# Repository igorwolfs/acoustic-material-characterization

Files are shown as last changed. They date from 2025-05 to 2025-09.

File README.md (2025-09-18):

# acoustic-emissions-hw
Repository for my non-destructive mechanical measurement device.

## Project Goal
Being able to measure cracks and holes in welds and solid materials by measuring mechanical wave behavior in the material.

## Description
The project will consist of 3 boards
- acoustic-processing-hw (The compute-module)
- acoustic-preamp-hw (The preamp-module)
- acoustic-piezodriver-hw (The driver-module)

## The electronics demistified

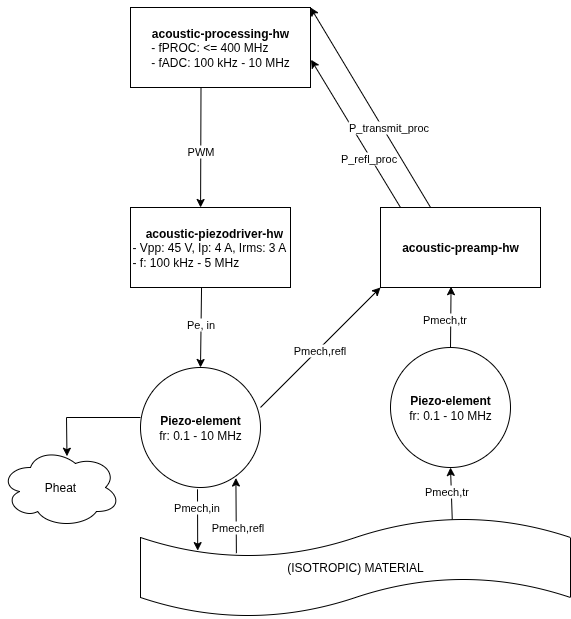
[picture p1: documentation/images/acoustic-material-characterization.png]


The **compute**-module will drive a PWM signal to the **driver**-module. The **driver** contains various DC-DC converters, along with a single-phase inverter. 

The inverter-output is connected to a piezo-element, driving the piezo-element with a 0.1 MHz - 10 MHz block-wave at an amplitude of 40 V, and currents up to 3 A RMS. Optional piezo-specific band-pass filters might be integrated.

The "transmitting" piezo-element and "receiving" piezo-element are connected to the **preamp** board, capable of
- Measuring transmitted power through the sending piezo.
- Measuring reflections back into the sending piezo (due to e.g.: mechanical impedance discontinuities between sending and receiving piezo).
- Measuring received power at the receiving piezo.

The **preamp** board will likely be covering only part of the 0.1-10 MHz frequency band. After some active filtering on the **preamp**-board, the signal is passed onto the front-end present on the **processing**-board. The **processing** board buffers the signal coming from the **preamp** and samples it with 10-bit accuracy at maximum 35 MHz.

## The mechanics demistified
#### Initial piezo-choice
The initial test-piezo used is the [UB161M7](https://www.mouser.de/datasheet/2/334/UB161M7-953231.pdf), which has a resonance frequency of 1.70 MHz.

#### Isotropic behavior
In order to get the best possible results, in terms of wave propagation insights and material properties. Ideally isotropic materials are used. Anisotropic materials will likely require lots of calibration and specific digital processing.

#### Piezo resonance frequency
In order to pass on vibration from the piezo onto the material, it's imperative to match their acoustic impedances. This will likely dampen the resonance curve, and shift the resonance frequency of the piezo.

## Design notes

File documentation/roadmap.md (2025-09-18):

# 1. Research
## Physics
### Wave mechanics
&#9745; Make sure you understand the terms in the wave equation
- &#9745;  The different types of waves (longitudinal vs transverse)
- &#9745;  Difference between elastic vs acoustic
	- Homogenous vs heterogenous materials

### Piezo-electrics
- Make sure you understand how the piezo-electric effect works
- how the piezo-electric material turns the mechanical energy into electrical energy on a molecular / atomic level.

## Piezo-electronics
- Choose the correct resonance frequency depending on the materials

# 2. Design
## Piezo
### Electrical simulation
- &#9745;  Create an equivalent resonant circuit for the piezo-element to use in LTSpice-simulations

### Mechanical simulation
- Think about mechanical adaptations for waterproofing / impedance matching / inital testing

## Driving electronics
### Driving inverter
- &#9745; Design / dimension the driving inverter and simulate in ltspice together with the piezo-electric
- Create in KiCad
	- Make sure to generate 12 volts from a buck converter
	- Add a possibility to simply supply the FET driver with volts in order to test shoot-through currents and things like that
		- This way you won't need to deal with those at 20 volts
- Add enough capacitance to supply the 10 amp current peaks to the piezo.

### Connector
- Choose an appropriate connector type for the driving part
	- Simply put 2 very big pads, one for each inverter side.
		- If needed solder some high-power connectors onto them / Make sure to have some holes ready.
	- Use a high-power twisted wire to connect them both.

## Analog front-end
### ADC selection
- Choose an ADC which can sample up to 10 MHz (so we can drive Piezo's up to 5 MHz)
	- Design circuitry around it, make sure it is isolated from the inverter

- Check design circuit for existing examples
	- Choose differential mode inputs
	- Choose Vref 2 Volt initially, make sure it's modifiable later-on to 1 V

### Pre-amplifier
- Design a preamp with a low source impedance to push the piezo through the cable
- Make sure you can integrate the preamp with the sensor
- Think about waiting with the preamp, and doing initial receiver measurements with an oscilloscope first.
	- Depending on whether you can fit everything on one board or not.

### Connector
- Choose an appropriate connector for transmitting the amplified signal.
	- See if you can use the same one for the driving part as you can for the sensing part (not necessarily)

## Digital electronics

### PWM generation
- Use an FPGA
	- Make sure to add dead time to the inverter

### FPGA Selection
- Check existing ultrasound projects using FPGA's, to see how the pipeline typically looks (e.g.: lit3rick, un0rick) -> done

#### Booting the FPGA
- Decide on how to boot the FPGA
	- Preview a JTAG connection
	- preview a QSPI memory interface
		- Quad-SPI, check the required configuration for the EC5
		- Check if there are any cores for the QSPI

# 3. Setup

## Piezo-electric transducer availability
- Buy the piezo-electric (UB161M7)
	- Buy at DigiKey: https://www.digikey.de/en/products/detail/pui-audio-inc/UB161M7/6071956
	- Circular shape, positive internal ring, negative external ring (good for shear waves)
	- resonance frequency: 1.7 MHz
- Characterize the piezo-element with a VNA
	- Check the source impedance, The resonance frequency, The resonance impedance
	- Make / Buy an SMA to 2-terminal adapter so you can simply connect your piezo-electric element.
	- Make sure to calibrate the end of the SMA using a 50 ohm resistance with MINIMAL PARASITICS
	- Encapsulate 2 of them in a transparent, electrically insulating layer (epoxy, RTV silicone, Parylene)
		- Make sure the impedance is appropriate for transferring vibrations to other materials.

## Driving the piezo
### Waveform
- Check if a bandpass filter is needed to filter out the high / low frequency components
	- We're getting pretty close to the limits of what the FET driver + FET can do at 4-5 MHz.

## Analog front-end adaptations

### ADC adaptations
- Depending on the Vpp coing out of your ADC
	- Adapt your Vref to 1 V instead of 2 V

### LNA design
- Perform this design after having the piezo-element receiver and measuring Vpp with an oscilloscope
	- If this Vpp is high enough

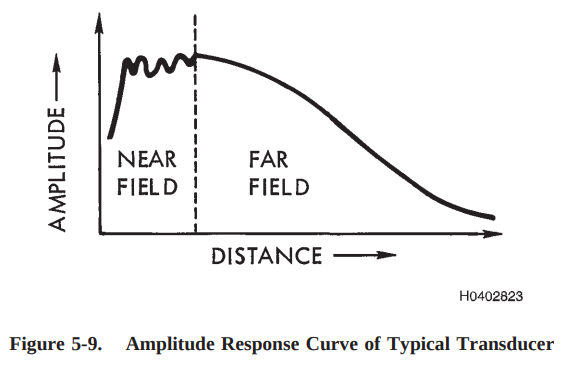
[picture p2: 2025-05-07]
piezo-research/theory/images/beam_spread.png

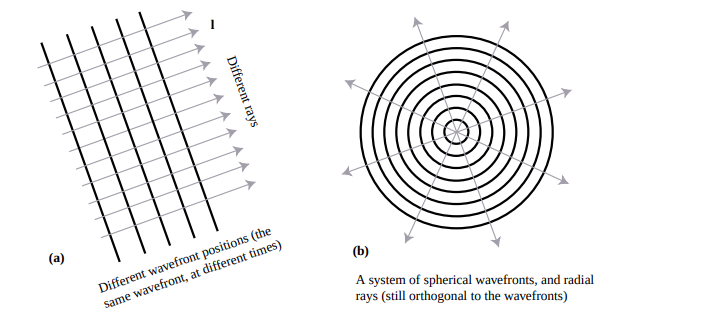
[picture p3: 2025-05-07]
piezo-research/theory/images/wavefronts.png

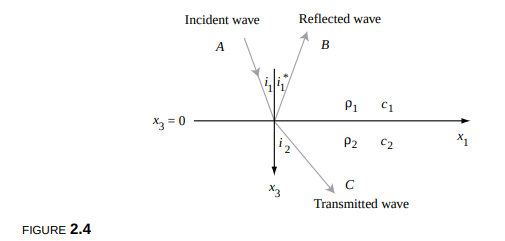
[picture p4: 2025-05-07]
piezo-research/theory/images/planar_interface.png

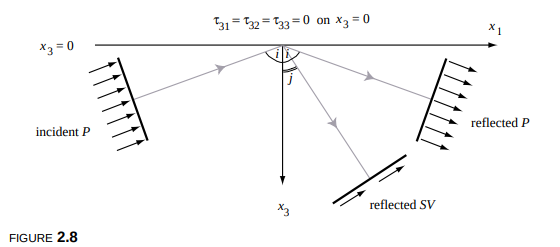
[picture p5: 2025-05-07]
piezo-research/theory/images/elastic_interface.png

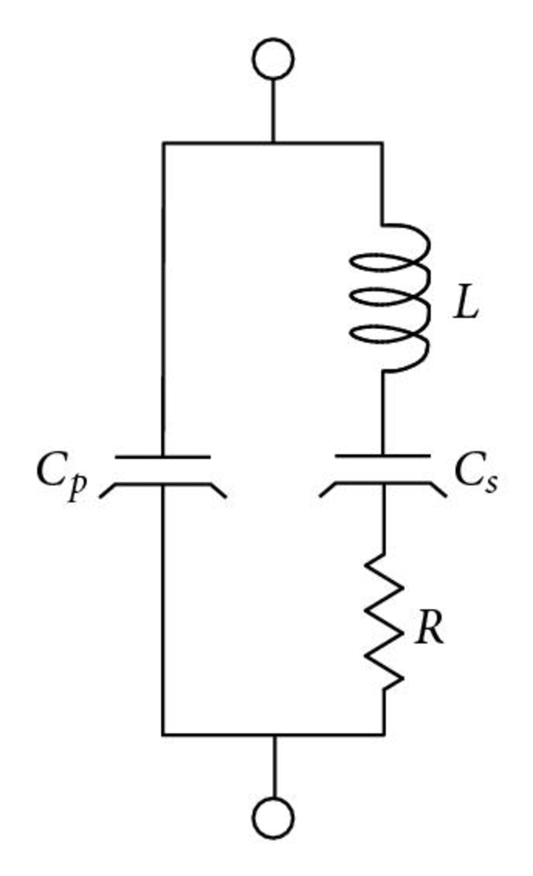
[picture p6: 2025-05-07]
piezo-research/theory/images/BVD.png

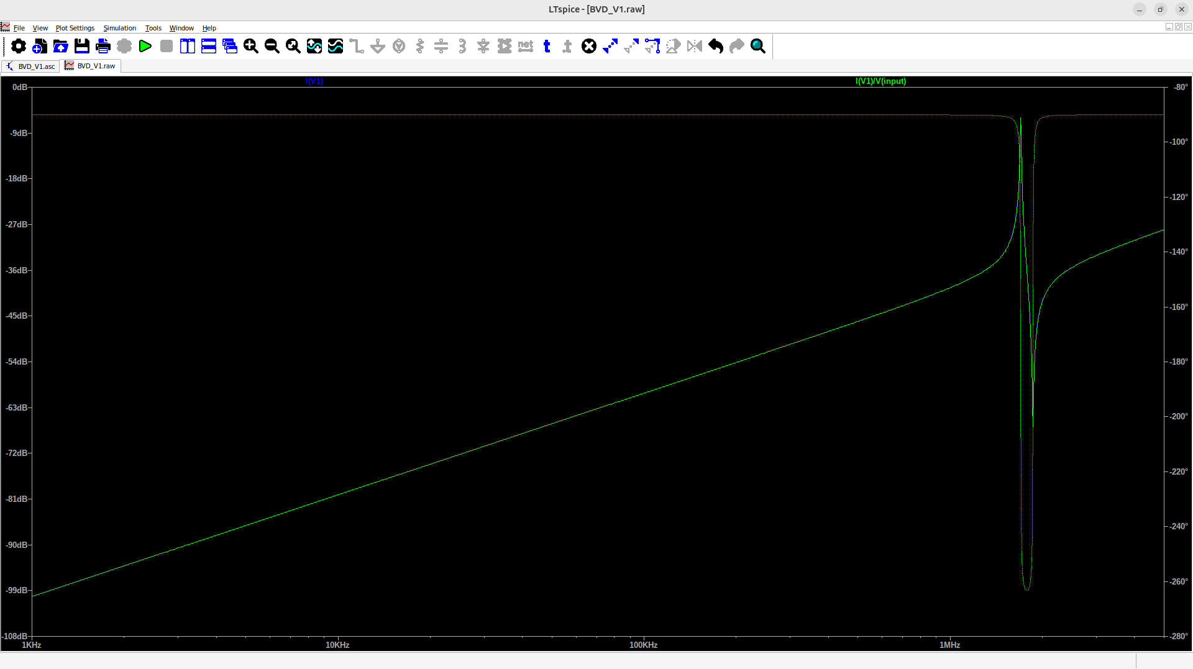
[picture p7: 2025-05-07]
piezo-research/write-ups/images/BVD_v1.png

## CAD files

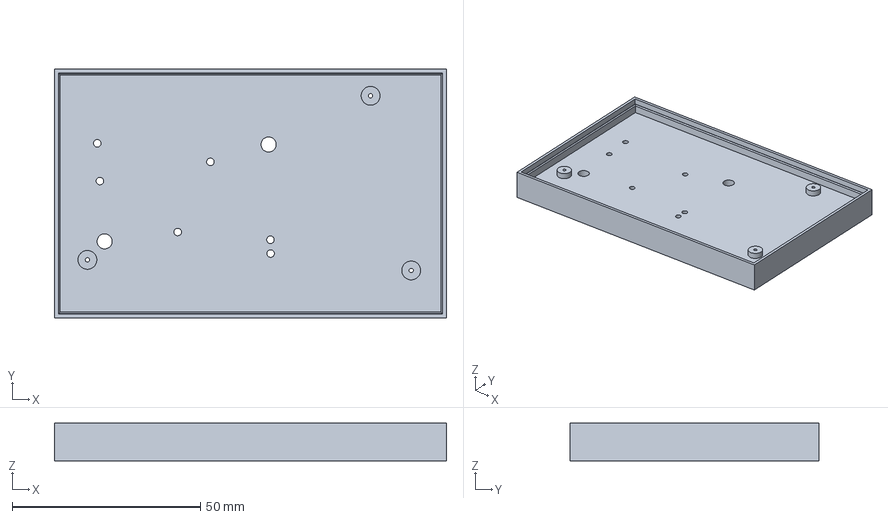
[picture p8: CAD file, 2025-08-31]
setup/cases/case_1/piezodriver_case.FCStd
104.0 x 66.0 x 10.0 mm

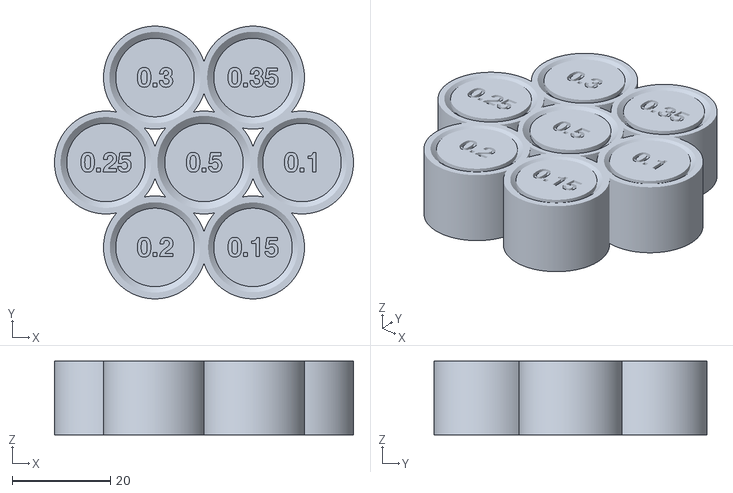
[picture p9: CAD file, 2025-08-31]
setup/cases/tolerance_tests/v2/tolerance_test.stl
61.0 x 55.6 x 15.0

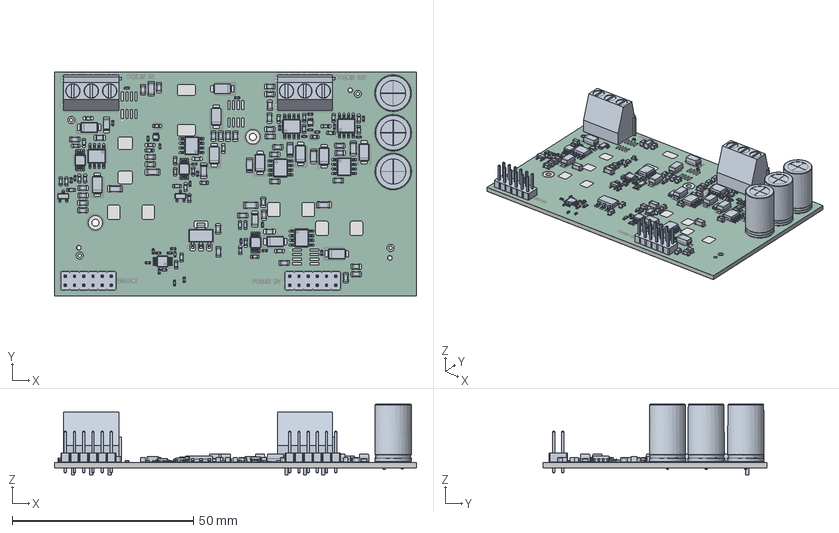
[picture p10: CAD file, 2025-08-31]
setup/cases/case_1/acoustic-piezodriver-board.step
100.0 x 62.0 x 19.5 mm
R_0603_1608Metric x 32
PinHeader_2x06_P2.54mm_Vertical x 2
C_0805_2012Metric x 34
C_0603_1608Metric x 3
C_0402_1005Metric x 24
R_0402_1005Metric x 8
VSSOP-8_3x3mm_P0.65mm x 3
D_SMA x 11
TerminalBlock_Phoenix_MKDS-1,5-3-5.08_1x03_P5.08mm_Horizontal x 2
C_Radial_D10.0mm_H16.0mm_P5.00mm x 3
LED_0603_1608Metric x 2
SOIC-8_3.9x4.9mm_P1.27mm x 7
TSSOP-10_3x3mm_P0.5mm
R_1206_3216Metric x 7
SOT-563 x 2
C_1206_3216Metric x 5
R_0805_2012Metric x 2
SOT-223
SOT-23 x 2
acoustic-piezodriver-board_pad
acoustic-piezodriver-board_silkscreen
acoustic-piezodriver-board_soldermask
acoustic-piezodriver-board_PCB

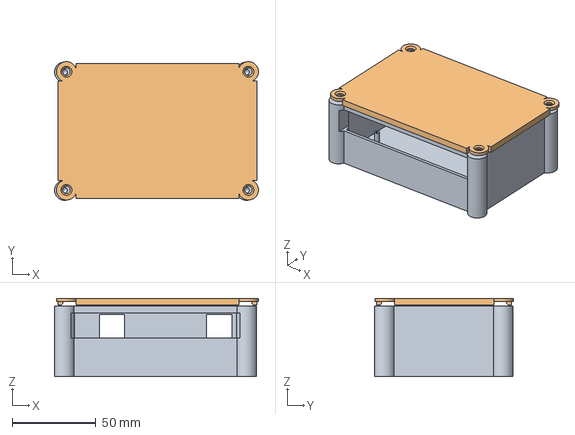
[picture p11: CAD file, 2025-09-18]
setup/cases/case_3/case_2.FCStd
121.6 x 82.7 x 46.7 mm
bottom
lid

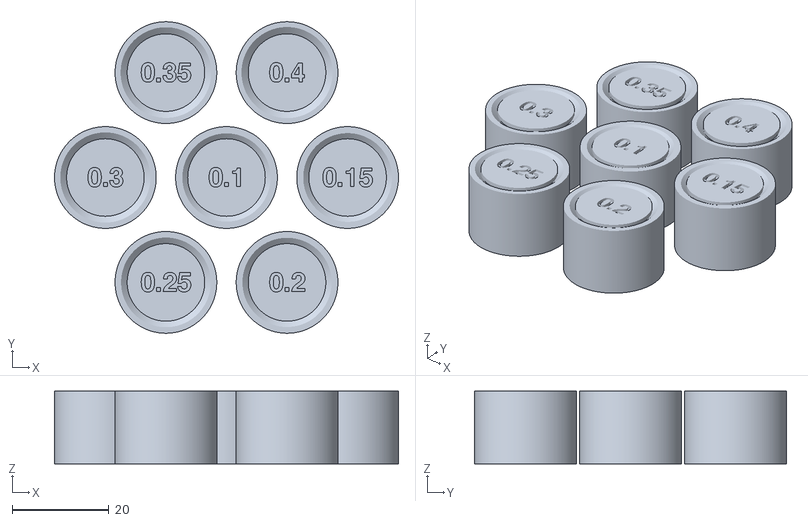
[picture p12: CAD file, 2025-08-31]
setup/cases/tolerance_tests/v2/tolerance_test_multi.stl
71.0 x 64.3 x 15.0

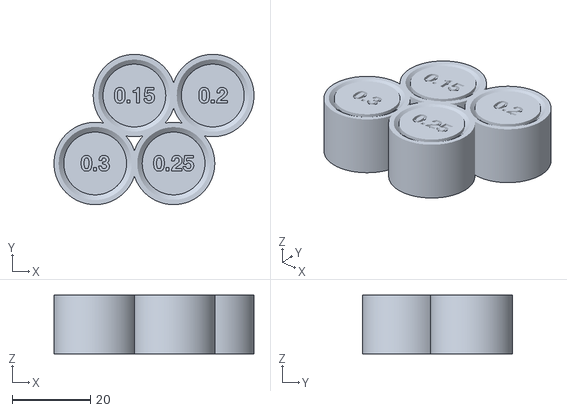
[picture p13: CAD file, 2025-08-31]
setup/cases/tolerance_tests/v2/tolerance_test_small.stl
51.0 x 38.3 x 15.0

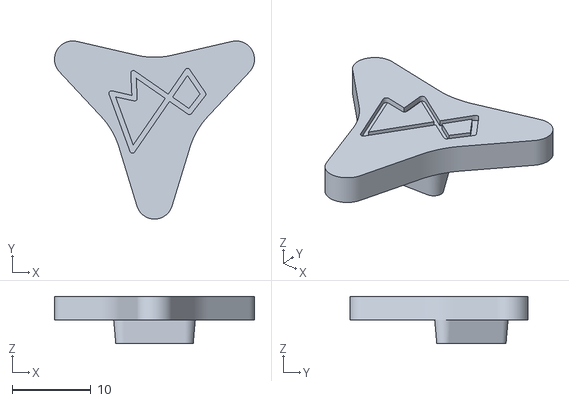
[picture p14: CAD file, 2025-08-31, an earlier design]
setup/cases/tolerance_tests/v1/KEY.stl
25.5 x 22.7 x 6.00

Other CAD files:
setup/cases/case_3/assembly.FCStd
setup/cases/tolerance_tests/v1/Tolerance Test File V3.stl
setup/cases/tolerance_tests/v2/tolerance_test.scad

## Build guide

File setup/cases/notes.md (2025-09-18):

# Tolerances
- https://formlabs.com/eu/blog/3D-printing-tolerances-for-engineering-fit/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
## Types of fits
### Clearance fit
Tolerance allows movements
- Tolerance zones don't intersect

### Transition fit
Easy assembly and dissasembly
- Tolerance zone partially intersect

### Interference fit
Rigid, strong connection. Tolerance zones fully intersect.
- Tolerance zones fully intersect

Note: requires use of materials with greater elongation.

## Tolerance tests
Print the stl-files in the tolerance_test-folder
- https://www.thingiverse.com/thing:2318105

# Screws
## 3D printing threads

Largest thread-size advisable for 3D printing:
- M6 and larger

## Metal threaded inserts
### Heat set inserts
However
- You need a soldering iron
- Sometimes hard to get them straight
	- Linear axis guides are often used for this stuff
- So quite some work per hole

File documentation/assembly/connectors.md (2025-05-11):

# 

# Board Mounting location
For the correct board mounting position, it's important for it to be
- Mechanically solid
- good EMI-wise

Since most of the power will probably be routed on the top layer, it seems better to
- Mount the power-board on top of the processing board
	- to avoid EMI issues.
- Mount the power-board sideways with the processing board
	- Clear visibility of the LED's and buttons on both processing and power-board

# Electrical considerations
## Major Power and ground connectionss
- There needs to be a good connection to ground right next to the power connection (minimal EMI issues)

## PWM connections
- We could make the PWM signal differential, which would eliminate the need for a return path.
	- However this would imply loads of analog circuitry

Consider using the 
- C7470109 (2x6 pins, 1.27 mm)

# Board mounting example repos
- PicoSat: Assembly of interconnected PCBs: https://github.com/Kmshanley/PicoSat-Initiative.git

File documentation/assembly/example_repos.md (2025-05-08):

# Board mounting example repos
- PicoSat: Assembly of interconnected PCBs: https://github.com/Kmshanley/PicoSat-Initiative.git

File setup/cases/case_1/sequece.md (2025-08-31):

# Simple Box
- Pass PCB dimensions:
	- PCB width
	- PCB height
	- PCB mounting hole coordinates (with respect to top left corner)
- Box wall thickness
- Arc-radius

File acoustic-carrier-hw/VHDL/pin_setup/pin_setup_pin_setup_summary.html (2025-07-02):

pin_setup project summary

Module Name: | pin_setup | Synthesis: | Lattice LSE

Implementation Name: | pin_setup | Strategy Name: | Strategy1

Last Process: | | State:

Target Device: | LFE5U-25F-6BG256C | Device Family: | ECP5U

Device Type: | LFE5U-25F | Package Type: | CABGA256

Performance grade: | 6 | Operating conditions: | COM

Logic preference file: | pin_setup.lpf

Physical Preference file: | pin_setup/pin_setup_pin_setup.prf

Product Version: | 3.14.0.75.2 | Patch Version:

Updated: | 2025/07/02 18:22:55

Implementation Location: | /home/iwolfs/Work/Projects/electromechanical/acoustic-material-characterization/acoustic-carrier-hw/VHDL/pin_setup

Project File: | /home/iwolfs/Work/Projects/electromechanical/acoustic-material-characterization/acoustic-carrier-hw/VHDL/pin_setup.ldf

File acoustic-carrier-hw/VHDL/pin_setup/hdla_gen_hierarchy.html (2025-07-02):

Setting log file to '/home/iwolfs/Work/Projects/electromechanical/acoustic-material-characterization/acoustic-carrier-hw/VHDL/pin_setup/hdla_gen_hierarchy.html'.
Starting: parse design source files
(VERI-1482) Analyzing Verilog file '/home/iwolfs/lscc/diamond/3.14/ispfpga/userware/unix/SYNTHESIS_HEADERS/ecp5u.v'
Done: design load finished with (0) errors, and (0) warnings

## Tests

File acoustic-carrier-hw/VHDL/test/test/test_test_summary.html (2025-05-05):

test project summary

Module Name: | test | Synthesis: | Lattice LSE

Implementation Name: | test | Strategy Name: | Strategy1

Last Process: | | State:

Target Device: | LFE5U-25F-6BG256C | Device Family: | ECP5U

Device Type: | LFE5U-25F | Package Type: | CABGA256

Performance grade: | 6 | Operating conditions: | COM

Logic preference file: | test.lpf

Physical Preference file: | test/test_test.prf

Product Version: | 3.14.0.75.2 | Patch Version:

Updated: | 2025/05/04 20:28:35

Implementation Location: | /home/iwolfs/Work/Projects/electromechanical/acoustic-characterization-hw/VHDL/test/test

Project File: | /home/iwolfs/Work/Projects/electromechanical/acoustic-characterization-hw/VHDL/test/test.ldf

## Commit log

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2025-04-27 [simulations] Updated sim with new values [kicad] Added inverter circuitry to schematic, add bulk capacitor LCSC parts, add pads for power connections.
    [inverter.kicad_sch]
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2025-04-29 [kicad, documentation] Set pin configuration, kept possibility open for reference voltage change and top/bottom, center, differential mode
    [acoustic-characterization-hw.kicad_sch, analog_frontend.kicad_sch]
2025-04-29 [documentation, kicad] Added decoupling capacitors + input circuitry for adc (next) Look for a decent connector
    [analog_frontend.kicad_sch, inverter.kicad_sch]
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2025-05-01 [kicad] Added connector + input circuit (next) Simulate adc input circuit in ltspice
    [analog_frontend.kicad_sch]
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2025-05-04 [kicad] Added initial config and jtag circuitrtry, added kicad symbol, added pinout + script for functionality checking (next) add qspi flash for boot
    [FPGA-SC-02033-2-0-ECP5U-25-Pinout.csv, acoustic-characterization-hw.kicad_sch, analog_frontend.kicad_sch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]
2025-05-04 [kicad] Added flash memory + flash connection (next) Add RAM and ethernet
    [processing.kicad_sch]
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2025-05-06 [kicad] Connected DDR3L bus, added info on FPGA and ddr pin functionality (next) add filtering circuitry for DDR power pins
    [analog_frontend.kicad_sch, inverter.kicad_sch, power.kicad_sch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]
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2025-05-06 [simulations] Added buck converter simulations (next) Completely understand voltage swing reasons and stabilize
    [TLV62569P_TRANS.DSN, ram.kicad_sch]
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2025-05-08 [carrier] Finished buck converters + simulations (next) Connect power to FPGA + add decoupling and bulk capacitance
    [power.kicad_sch]
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2025-05-09 [carrier] Added space for ferrite bead in between bulk and decoupling caps
    [power.kicad_sch]
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2025-05-10 [carrier] Added usb power + communication circuitry (next) Connect ADC pins to bank 0, select PWM pins, check connectors for power board
    [analog_frontend.kicad_sch, communication.kicad_sch, inverter.kicad_sch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]
2025-05-10 [carrier] Finished basic ADC connections (next) decide on connections with power board
    [analog_frontend.kicad_sch, ram.kicad_sch]
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2025-05-12 [piezo-driver] Doing boost converter simulations (next) fix weird transient, add buck-converter simulations for 10 and 5 V
    [acoustic-carrier-board.kicad_pcb]
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2025-05-18 [piezodriver] Added X7R input capacitor, add input and output capacitance of 40-100 uF
    [inverter.kicad_sch, power.kicad_sch]
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2025-05-19 [piezodriver] Finished 2 sepic designs, starting boost design (warn) Make sure to max diode voltage difference
    [power.kicad_sch]
2025-05-19 [piezodriver] Choose smaller inductor with larger current carrying capacity, increase switching frequency (but check LM3478 limits)
    [power.kicad_sch]
2025-05-20 [piezodriver] Finished boost converter simulation and part selection, working on compensation circuit and control loop
    [power.kicad_sch]
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2025-05-20 [carrier] Reordered carrier board (next) add magnetics to adc differential and ethernet instead of capacitors - SRF is too low
    [analog_frontend.kicad_sch, fpga_pinout.csv, inverter.kicad_sch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]
2025-05-20 [carrier] Reorganized carrier board schematic, added lcsc part numbers (next) check schematic before component placement
    [analog_frontend.kicad_sch, communication.kicad_sch, power.kicad_sch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]
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2025-05-24 [carrier] Added second adc input with magnetics, added ethernet connector with magnetics [piezodriver] Added diodes to level shifters for gate charge return current
    [analog_frontend.kicad_sch, communication.kicad_sch, inverter.kicad_sch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]
2025-05-24 [piezodriver] Added temperature sensors + ldo + 8x2 connectors to carrier board
    [analog_frontend.kicad_sch, inverter.kicad_sch, power.kicad_sch]
2025-05-24 [carrier] Started schematic check, replaced 8 with 16 pin connectors
    [analog_frontend.kicad_sch, communication.kicad_sch, power.kicad_sch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]
2025-05-25 [carrier] removed external led, using ethernet leds, replaced 1kOhm by 470 ohm resistors
    [analog_frontend.kicad_sch, communication.kicad_sch, power.kicad_sch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]
2025-05-25 [carrier] Fixed most of the carrier board ERC issues (next) fix BGA ERC issue
    [acoustic-carrier-board.kicad_sch, analog_frontend.kicad_sch, communication.kicad_sch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]
2025-05-25 [carrier] Fixed ERC errors and fpga-footprints (next) ) add extra pin functionality to 2 remaining banks, perform schematic checks
    [acoustic-carrier-board.kicad_sch, analog_frontend.kicad_sch, communication.kicad_sch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]
2025-05-26 [carrier] added rudimentary LC filter at input (next) - provision signal generator input
    [analog_frontend.kicad_sch, communication.kicad_sch, fpga_connector.kicad_sch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]
2025-05-28 [carrier] Fixed differential source impedance at simulation, added chebyshev + butterworth filters
    [analog_frontend.kicad_sch]
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2025-05-29 [carrier] Chose amplifier, changed adc voltage range (next) change commmon mode source, add decoupling, add buffering to common mode
    [analog_frontend.kicad_sch, ram.kicad_sch]
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2025-06-01 [carrier] Added buffered VOCM (next) add switch on which was decided, add biasing after ac coupling caps, add provisionary pull-ups at of THS452 INPUT-
    [adc_connections.kicad_sch, analog_frontend.kicad_sch]
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2025-06-02 [carrier] Replaced voltage reference, added extra 0 ohm resistors, added test-connectors for ADC testing
    [adc_connections.kicad_sch, analog_frontend.kicad_sch]
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2025-06-02 [carrier] Fixed ERC issues, added PDn pin connection
    [analog_frontend.kicad_sch]
2025-06-02 [carrier] Added 100 MHz crystal oscillator (next) Do a component / footprint check
    [fpga_connector.kicad_sch]
2025-06-02 [carrier] Fixed minor symbol errors, added minor routing info (next) continue schematic check
    [adc_connections.kicad_sch, analog_frontend.kicad_sch, communication.kicad_sch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]
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2025-06-03 [carrier] Did additional tests with tina-ti and blocking cap, did schematic check up to adc input buffer
    [analog_frontend.kicad_sch]
2025-06-03 [carrier] analog frontend check DONE, (next) check config and boot-flash pin connections
    [analog_frontend.kicad_sch]
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2025-06-03 [piezodriver] Added tina-ti simulation of 10V sepic (next) fix this sim, add power circuitry sim for carrier in tina-ti
    [power.kicad_sch]
2025-06-04 [carrier] Further verification of power board (next) Replace ddr3l reference voltage using TPS51200
    [power.kicad_sch, ram.kicad_sch]
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2025-06-08 [carrier] Doing schmitt trigger calculations and simulations, choosing comparator, choosing USB connector
    [communication.kicad_sch, usb.kicad_sch]
2025-06-08 [carrier] Finished schmitt trigger for cc1 and cc2 led driver + passive power signalling
    [usb.kicad_sch]
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2025-06-09 [carrier] Reorganized schematic, moPut adc signals in bus, fixed DRC errors (next) recheck ethernet, check usb, add power switch
    [acoustic-carrier-board.kicad_sch, adc_connections.kicad_sch, communication.kicad_sch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]
2025-06-10 [carrier] Fixed error in ethernet power supply, separated footprints + symbols into library (next) check whether supply should be DVDDH
    [adc_connections.kicad_sch, communication.kicad_sch, fpga_connector.kicad_sch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]
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2025-06-10 [carrier] Finished switch and reverse voltage circuit
    [power.kicad_sch]
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2025-06-11 [¢arrier] Fixed busses, added resistive arrays instead of 4x4k7 or 4x10k
    [acoustic-carrier-board.kicad_sch, adc_connections.kicad_sch, communication.kicad_sch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]
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2025-06-11 [carrier] Added extra decoupling to ECP5U according to datasheet (next) perform page-wise checks, add testpoints
    [acoustic-carrier-board.kicad_sch, connectors.kicad_sch, fpga-bank-01.kicad_sch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]
2025-06-12 [¢arrier] Did major cchecks of ETH, DDR, ANALOG, config (next) check buffer circuit driven by USB-CC, then start layout
    [analog-frontend.kicad_sch, ddr3.kicad_sch, ethernet-phy.kicad_sch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]
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2025-06-12 [¢arrier] Checked stackup theory, return current theory (next) continue researching ideal stackup
    [fpga-config-flash.kicad_sch]
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2025-06-17 [¢arrier] Added netties and determined trace geometry for 50 ohms SE / 100 ohms DIFF impedance (next) reset the appropriate DQS group signals, RGMII and USB signals
    [acoustic-carrier-board.kicad_pcb, analog-frontend.kicad_sch, fpga-bank-01.kicad_sch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]
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2025-06-19 [carrier] Changed non-inverting to inverting schmitt trigger configuration to limit the buffering requirement
    [usb-phy.kicad_sch]
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2025-06-27 [carrier] Progressing on ddr3 routing (next) check all ddr3 signals for errors, start length matching
    [acoustic-carrier-board.kicad_pcb, fpga-dqbank-23.kicad_sch]
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2025-07-10 [carrier] Added delayed startup + some traces (next) fix the errors inside the DDR3 routing somehow
    [acoustic-carrier-board.kicad_pcb, analog-frontend.kicad_sch, power.kicad_sch]
2025-07-11 [carrier] DRC fixes
    [acoustic-carrier-board.kicad_pcb]
2025-07-11 [carrier] Corrected most of the DRC errors, a few tens left + respacing DDR3-traces
    [acoustic-carrier-board.kicad_pcb, analog-frontend.kicad_sch, fpga-config-flash.kicad_sch]
2025-07-13 [carrier] Fixed most routing errors
    [acoustic-carrier-board.kicad_pcb, analog-frontend.kicad_sch]
2025-07-13 [carrier] Fixed drc errors (next) do final checks (including length checks on clk)
    [acoustic-carrier-board.kicad_pcb]
2025-07-13 [carrier] Fixed last errors, redid length matching for LPDDR3
    [acoustic-carrier-board.kicad_pcb, acoustic-carrier-board.kicad_sch]
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2025-09-29 added notes on bringup (next) try pinpointing the location by zooming into short
    [assembly.FCStd, case_2.FCStd]
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
